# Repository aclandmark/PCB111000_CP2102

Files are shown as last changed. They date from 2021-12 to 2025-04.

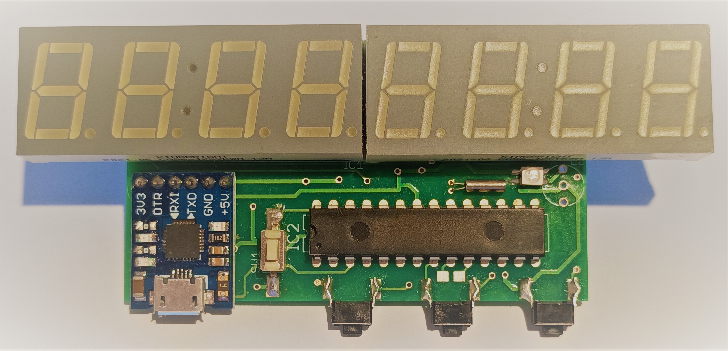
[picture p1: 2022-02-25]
Documents/Photos/PCB_photo_TOP_4.jpg

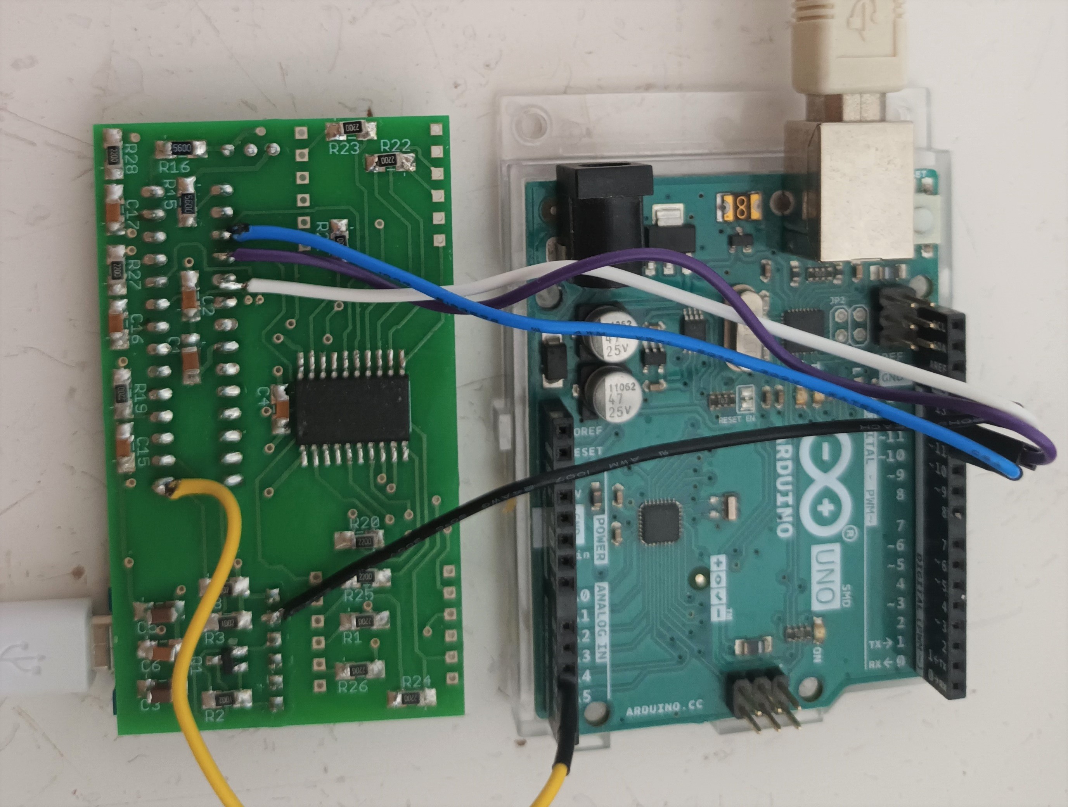
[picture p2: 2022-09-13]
Documents/Photos/Programming_sys_FW_copy.jpg

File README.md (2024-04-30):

# PCB111000_CP2102

PCB111000 has beeen developed as a learning aid for the C language when applied to AVR devices.  
It consists of a USB bridge to communicate with a PC, an 8 digit display and two AVR devices. 
One of the AVR devices (Atmega 328) hosts a programmer and miniOS which drives the display, 
the other (Atmega168), the user device, hosts user projects.

An I2C bus is used to link the two devices.
All user projects are compiled using Arduino, system projects use Arduino or Studio 7 if needed.
The boards are set up using the UNO to host a bespoke programer.  See repository "UNO_as_an_AVR_programer". 

See repository "PCB-111000/1_Documentation/1_PCB 111000 leaflet.pdf" for general information and a block diagram of the original development. 

There are three versions of PCB111000:

PCB_111000_V2 using two Atmega devices and the FTDI FT230XS USB bridge  
PCB_111000_UNO_V2 A simplified plug in version for use with the UNO  
PCB_111000_CP2102 Using one Atmega one ATtiny and a CP2102 module for USB connectivity.  

In PCB_111000_UNO_V2 and PCB_111000_CP2102 the user device is an Atmega328 which hosts
a bootloader as well as the user projects.

In PCB_111000_CP2102 the I2C bus is replaced with a one wire firmware UART.

PCB111000_CP2102 is assembled using the following steps:

	Prior to assembly a UNO loaded with "UNO_AVR_Programmer" is used to
	program an Atmega328:
	
		With a routine that will be used to calibrate the internal 8MHz clock
		and will then be deleted.
		With a bootloader that will be used for all future programming operations
	
	Post assembly a UPDI programmer is uploaded to the Atmega328 which 
	enables the ATtiny1606 to be programmed with the miniOS.

	Calibration of the ATtiny1606 checked and adjusted if necessary
	
	The pcb is now ready to accept user projects.

	At any stage the UPDI programmer can be rienstated to upgrade the miniOS.

SW used to configure PCB_111000_CP2102  
UNO_AVR_Programmer :	see AVR freaks projects 9 Sept 2020 Slighytly modified  
UNO_UPDI_Programmer: 	Originally writen for the UNO but also runs with an 8MHz clock  
			and can be used here

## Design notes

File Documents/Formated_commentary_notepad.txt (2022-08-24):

***
Page 1   PCB_111000_CP2102 (or just the PCB):Press a/k to continue.

Learning with PCB111000 is based on playing with simple programs, getting familiar with the way they are written, understanding them and finally modifying them to make them our own. The programs drive an 8 digit display, generating patterns and numbers and pass data to and from a PC.

Before attempting to begin programming in earnest it is a good idea to read the Introduction and User Guide and of course download the applications suggested there.

Our first project a simple C program is based on JP's Blinky, see JP p30 and chapter 3.   A selection is offered here.  A free-bee is given, just to make sure that everything is working OK. Just follow the instructions given in the user guide.

Why not choose another and type it in. Verify the code and upload it to the pcb (remember Ctrl z, the most useful go back feature).

System crashes: Every effort has been made to prevent these, but if pulsing the reset control switch does not restore the p/r/t/D prompt reconnect the PCB to the PC with this switch held in.

Having got it working pressing Tools/Auto Format will make the code much clearer to read. Why not try several others and then take a look at them and notice a number of features:

#include "First_project_header.h"  	Click on it and see that it contains additional information required by the compiler, including other .h and .c files with essential definitions and resource subroutines  (pn is recommended for opening these). 

The main routine.  This is where the program starts when power is first applied or after a reset.	Move on the page 2 for more features (press a/k).*

***Page 2   More things to take note of in our C programs.		setup_328_HW (Hard Ware):This contains a block of code and is known as (k\a) a macro. Details are given in the header file.	HW requiring setup includes the data pins,	communication between the micros and with a PC	the reset control switch	and watch dog timer(WDT) which automatically reset the micro.	In addition sei() enables interrupts which are required by the one wire link (and will be discussed later).

Unsigned int PORT_1:PORT_1 is the name of a memory location that holds numbers.	The smallest element of computer memory is a bit and can hold either a 1 or a 0. 	Memory is often divided into blocks of 8 bits which can hold numbers between 0 and 255.	16 bits are reserved for PORT_1.	See JP chapter 4 for an introduction.

Hexadecimal numbers (i.e. 0x8000) in which 16 in ordinary counting is equivalent to 0x10 and 256 (16 x 16) is equivalent to 0x100. 	Arithmetic and logic symbols. 	JP gives full definitions of these topics in chapter 4.	However logic quickly gets rather involved and a quick look is all that is recommended at this stage. 

The for loop, the while loop and the if statement which are very important features of C. A good look at JP chapter 5 C Control flow is recommended before moving on from this first project.

Subroutines	One_wire_Tx_2_integers(PORT_1, PORT_1)	which sends data over the one wire link to drive the display.	PRN_16bit_GEN(0) which generates random numbers	Timer_T2_10mS_delay_x_m() which uses a HW timer to generate delays.		Note: Subroutines are called by the main routine or other subroutines. Here we define them as either resource subroutines which are for general use or project subroutines which are written for a particular project.  See JP page 87 chapter 6 for more on subroutines.

break and continue commands:  These are both executed when a particular condition is met.  Break causes the program to exit a for or while loop.  Continue causes it to skip a number of lines of code and jump back to the start of the loop.  See JP page 79.

SW_reset;	This is also a macro. It uses the watch dog timer (WDT) to reset the program so that it repeats endlessly.

Before leaving example 1 why not comment each line stating what it does as a learning aide (See JP p39). 

Having looked at the examples why not mix and match to compose your own code.*

***Page 3   Talking to the PC, introducing the USART (Universal .... Receiver Transmitter module).		Many devices have a receiver transmitter module for communicating with a PC.	See JP page 98 chapter 6 for a few details.	Arduino provides a comprehensive set of functions for using the USART. 	Here basic do it yourself (DIY) functions are used.	This approach provides a good introduction to the data sheet, a vital resource for setting up other things such a timers and interrupts. 

Take a look at subroutine Char_to_PC_Local() and see section 20.11.1 of the data sheet.	UDR0 is the input output (I/O) data register for the USART, it has 16 bits, 8 for write operations and 8 for read.	Data written to UDR0 will automatically be transmitted.	Data that has been received can be obtained by reading UDR0.	UCSR0A is the Control and Status Register A.	UDRE0 (bit 5 of register UCRS0A) is a flag which is set when UDR0 is empty and can accept new data for transmission.	RXC0 (bit 7) is a flag which is set when data has been received and can be read. 

A number of these DIY functions can be found in	Resources_Receiver_transmitter\Basic_IO_and_Timer	They are best viewed using programmers notepad (pn).*

***Page 4   Nine sample programs that transfer data to and from the PC are offered.		A look at each is recommended.	Example 1 simply echoes keypresses to the screen.

Example 2 prints many of the common characters to the screen.	Clicking on the hex button in the receive section of the Bray window shows that each character is represented by a number. See JP p283.

Example 3 prints a file.	Resource "isCharavailable(65)" returns a 1 immediately if a character is received in a 1 second window. Otherwise it returns zero and is called again.	Having received the first character it can then receive any number but will exit (break) if no character is received after a pause of 154mS.

Example 4 introduces character strings and shows they can be sent to the PC.	It also shows how they are stored in arrays (consecutive locations) in memory.	We compose the strings and choose a name for each one.	The compiler adds a 0 to the end of each string.  It also replaces the names (i.e.  message_1) with the address of the first character in the string.	Note the two ways of writing the appropriate the C statements:	The * character indicates that memory location message_1 holds an address.	The [ ] characters indicate that message_3 is an array of characters.	See page 5 for more UART examples.*

***Page 5 More examples of data going to and from the PC.		Example 5 simply prints out the characters together with their numeric equivalents.	Example 6 Converts a number to a string of characters and sends them to the PC and example 7 does the reverse.	These are two very important operations. Take time to understand what is going on. See JP pages 81 to 84 for some help.

Example 8 Uses project subroutines to: Accept a numerical string from the keyboard, convert this to a number which it doubles, reconvert the result to a string and send this to the PC.	All the strings are stored in array Num_string which has 12 memory locations. The subroutines require the address of the first element in this array (hence the use of the * symbols).	Variables preceded by the * symbol are k/a pointers.  See JP ch. 8 for a discussion of pointers.

Example 9 uses repeated division to convert a fraction to decimal.	It calls subroutine divide() which returns the number of outstanding decimal places. It also calculates the result of the division and the remainder (modulo see JP page 51).	Memory for these two variables is provided by the main routine.	The & symbols indicate that the subroutine will not be providing memory for these variables.  It is the address of each variable that is being passed to the subroutine not its value.

As an alternative to the use of pointers (i.e. the * and & symbols), variables can be declared in the header file rather than in the main.  This may be OK for small projects but is not normally considered good practice (see JP page 90).*

***Page 6   Using interrupts: 5 examples are given.		See JP chapter 7 p109 for a general introduction to interrupts.	3A does some calculations and prints out the results when sw2 is pressed. A HW timer running in the background interrupts this process every 100mS. The micro jumps to the ISR (interrupt service routine) and updates the display.	A key press interrupt is also shown enabling users to to manipulate the display manually.	We see that the interrupt enables 2 processes to run at once.

Look at the 100mS_clock_tick() subroutine.	The timer is configured as a counter which counts from 0 to 12500.	TCCR1B sets a timer clock to 125KHz so it takes 100ms to complete counting, raise an interrupt and start again.	Open up the data sheet section 16.11 to see the registers. We leave most of them alone but set TCCR1B, TCNT1, OCR1A and TIMSK1.

3B Target practice looks at interrupts generated by pressing one of the user switches.	PCI stands for pin change interrupt.	Look at the header file for definitions of the macros.	See the data sheet sections 13.2.4 and 1 for details of the PCI registers.

3C Reaction time tester:Nothing new here, just included for a bit if extra practice.	Press SW2 and release immediately that the leds line up to get the display to flash.

3D Multi display:This includes PCI and timer interrupts as well as the one wire comms interrupt.	Multiple interrupts can easily cause trouble. To avoid this the PCI also resets the micro. Before doing so it writes to the EEPROM. After the reset it reads the EEPROM so that it knows which switch was pressed.	EEPROM is a special area of memory that survives power down and reset, which both usually result in all registers being reset to zero.

3E Is an interrupt driven key press logger that also drives the display.	Projects 3D and E include the volatile declaration. This is because variables are being changed by an ISR.  Unlike for a subroutine the compiler cannot anticipate that the ISR will be called. The variables are therefore declared to be volatile as a warning to the compiler.*

***Page 7   Exploring logic and binary operations.		Two programs Bit_ops_1 and 2 are used to demonstrate how individual bits can be read, set, reset or changed.	These operations are needed to configure HW items such as the USART, and Timers and also to monitor their status (i.e. is there USART data waiting to be received).

Bit_ops_1 uses the display and random number generator to investigate the AND, OR, Exclusive OR and NOT operations.	Bit_ops_2 combines these operations with the shift function to set or read individual bits.

As a practice exercise in logic, multiple addition and subtraction are used in program_3 to implement multiplication and division (these operations are usually carried out in HW or by compiler generated code). 

As a final example the display is used to display positive and negative 8 bit numbers in binary and decimal form.*

***Page 8   Using the Arduino PC comms library:		Arduino provide a suite of programs that pass data to and from a PC. These will probably be the sensible choice for use with the Arduino compiler.	Integer and floating point numbers are supported.	Easy extension to include scientific numbers is implemented in these examples.

Three additional examples are included:	The first explores prime numbers. The theory for these was developed by the ancient Greeks. Their method for obtaining them is still probably the best for us use here. 

The second provides an estimate for pie.  The area of a circle is computed by placing it over a fine grid of squares and counting them.	

The third uses a power series to compute log/antilog functions so that any positive scientific number can be raised to an arbitrary power.   If the result is either too large or small the program times out.  An interrupt is generated and the resulting ISR, writes to the EEPROM, before issuing a SW_reset.	When the program resets it reads the EEPROM and issues the appropriate user prompt.*

***Page 9   The 8 digit display and IO:		Obviously Arduino does not provide library functions to drive the display, so it is necessary to revert to DIY programming.	The purpose of the first 2 programs is to demonstrate how numbers are constructed from the display segments.	Program 3 defines each digit in terms of a string as has previously been done with messages.	The user enters a digit at the PC.	The appropriate string is selected.	Segments defined by the string are are illuminated.

In the remaining projects the complexity of driving the display is handled by the mini-OS that resides on the Attiny1606.	Two of these are used to enter data from the PC keyboard and two from the user switches.*

***Page 10   Timers    Here a selection of timers/clocks are developed.		Accuracy is provided by a watch crystal that beats 32768 times a second.	Register TCCR2B (see section 18.1.2) is used to reduce the crystal frequency to 1024 beets per second which are counted by timer/counter T2.	The counter advances by 102 in 99.61mS (~100mS) after which an interrupt is raised.	It advances by 918 in 896.5mS (~900mS).	To ensure accuracy over a 1 second interval the counter must advance by a further 106 (103.5mS) before the 1 second interrupt is raised.

In the first example time is simply recoded as a string, and in the second a counter is set up that records elapsed time in seconds. In the third example much of the time keeping burden is transferred to the mini-OS.	Two more examples are included,  one is a stand-a-lone clock, in which time is entered and adjusted using the user switches and the other is a stop watch.*

***Page 11   Reset options		The HW includes a timer k/a the watch dog timer (WDT).  This counts from zero to a user defined value after which it issues a reset pulse.   Provided that it is reset frequently enough there need be no reset.  

Arduino offers three modes for the WDT.		It can be initiated as in the macro "setup_watchdog" (see the project header file).	If it is allowed to time out the project will be reset.		It can be initiated with an interrupt (see for example "One_25ms_WDT_with_interrupt").	The ISR (interrupt service routine) might write to EEPROM before issuing a SW_reset.		If the ISR is missing program control willl jump to location 0x0000, the start of the program.	This is important for us because a reset takes program control to the boot loader not the start of the user project (0x0000).

PCB111000_CP2102 uses the macro "SW_reset" to implement a planned reset.	It uses "One_25ms_WDT_with_interrupt" with no ISR to recover from an unplanned reset or system crash.

The micro includes an MCU status register (MCUSR).	This records the source of the reset which can be	POR (power on reset)	WDT	External reset (not used here)	Low supply voltage (not used here).	The bootloader reads this to determine whether the reset is due to the WDT or POR	It uses the EEPROM to determine whether to jump to the user program or continue with the bootloader.

Example 8A explores the basic operation of the reset function provided by PCB111000_PC2102	

Example 8B sums cosine waves to generate a pulse function.  This is an example of the micro working flat out with an 8MHz clock.  No wonder many applications require a much faster clock.  The various reset functions are used to control its operation.*

***Page 12   That's it for PCB11000_CP2102:	Much ground still to cover, many new things to explore, but hopefully enough ground has been covered to wet the appetite for more detailed and systematic study.

Click on Arduino Help/Reference to see that we have barely scratched the surface of what Arduino has to offer.	There is of course also the Atmel Studio free development system.  I would certainly not want to be withour either.	

Of course the great strength of the UNO is that it comes with a bootloader.	However why not experiment with UNO_AVR_Programmer also posted on AVR freaks.	Even download free PCB design SW and make your own board!*

***Page 13   Not used.*

***Page 14   Not used.*

***Page 15   Not used.*

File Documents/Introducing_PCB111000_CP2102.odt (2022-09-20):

Introducing PCB111000_CP2102

PCB111000_CP2102 is a cut down version of PCB_111000_UNO posted by osbornema on 18 July 2020. It is designed to provide an introduction to C programming for AVR devices and consists of:

A CP2102 module with Rx/Tx and power provided on a 6 pin header

An Atmeg328 for user programs

An ATtiny 1606 that drives an 8 digit seven segment display.

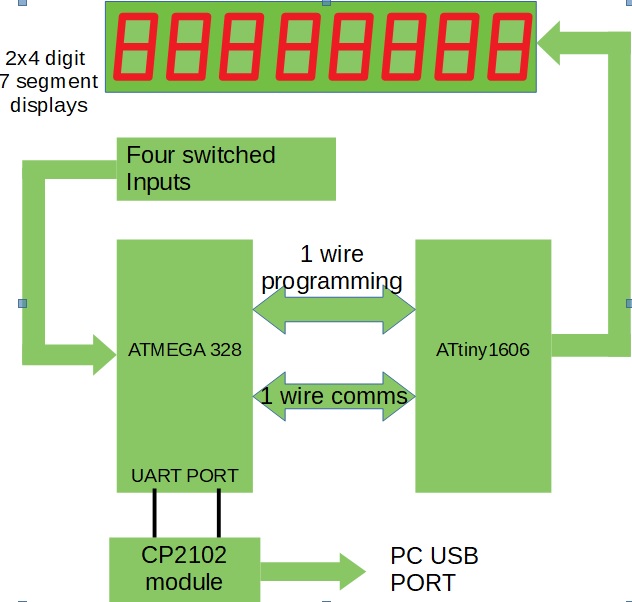
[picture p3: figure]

| System diagram for PCB111000_CP2102 The Atmega 328 hosts: A Hex/text bootloader An optional UPDI programmer User programs Text commentary for several sample programs. A default program provided for test purposes. The ATtiny1606 Drives the display Provides resources for the user projects One of the switches controls reset and display intensity. The others are or data entry.

System projects

| Name | Compiler | Platform | Task
1 | UNO_programs_328 | Arduino | UNO | Uploads bootloader and provides time standard for Atmega 328 calibration.
2 | UNO_Calibrates_328 | Arduino | Atmega328 | Calibrates 328 against the UNO crystal
3 | CP2102_UPDI_Programmer | Arduino | Atmega328 | Uploads mini-OS to ATtiny1606
4 | CP2102_mini-OS | Studio 7 | ATtiny1606 | Drives display and provides user services
5 | cal_one_wire_comms | Arduino | Atmega328 | Matches 328/1606 baud rates
6 | CP2102_bootloader | Studio 7 | Atmega328 | Loads user projects and reads the commentary
7 | FP_arithmetic | Arduino | Atmega328 | Test project
8 | Recal_328_using_crystal | Arduino | Atmega328 | Check calibration post pcb assembly

Note: All projects are closely based on previous versions already posted on AVR freaks.


| Fig 1 Photos of PCB111000_CP2102 Note that tracks are provided for either surface mount or leaded Red/Green LED and watch crystal The vertical switch is the reset control switch. The horizontal switches are user switches sw1, sw2 and sw3 counting from the middle of the pcb. RX/Tx leds on the CP2102 module can be disabled if they are found to be too bright by removing their series resistors as in the photograph.

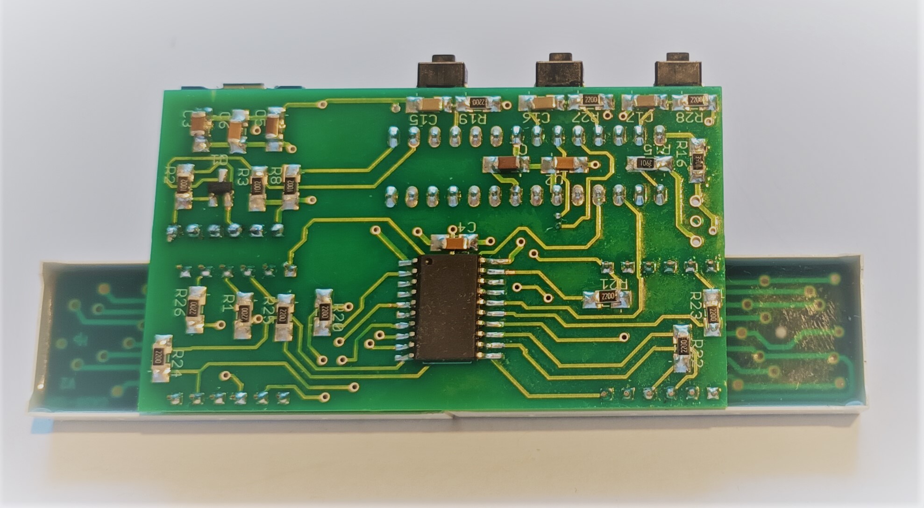
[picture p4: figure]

The Project PC

There are two essential software applications that must be downloaded onto this PC. They are:

The Arduino development environment. Go to https://www.arduino.cc/en/software and download it from the Microsoft store.

Bray++ version 20130820 which can be downloaded from https://www.sites.google.com/site/terminalbpp/

Almost as important are

The portable version of Programmers notepad which can be downloaded from

http://www.pnotepad.org/download/.

An excellent text written by Joe Pardue that can be downloaded from

https://epdf.pub/c-programming-for-microcontrollers.html

The Atmega data sheet that can be downloaded from

https://www.docdroid.net/Q6jfzd3/atmega48a-pa-88a-pa-168a-pa-328-p-ds-ds40002061a-pdf

PCB manufacture: Generating the Gerber files

The Eagle pcb design tool must first be downloaded.

A free version is available from Autodesk which can be used to process two layer boards of a limited size. Go to https://www.autodesk.com/products/eagle/free-download

Place the Eagle board and schematic files in any suitable folder (to be referred to as the Project directory).

Open the Eagle control panel

Click on CAM Jobs then examples and double click on example_2_layer.cam

Tick the Export to Project Directory box

Click on Select board

Navigate to the project directory and open the board file

Click on Process Job then Open folder

A CAMOutputs folder should have been added to the project directory. This will contain the Gerber and drill files needed to get the pcb manufactured.

Recommended PCB assembly steps

Solder on all SM resistors, caps, the FET and the ATtiny 1606 to the pcb underside.

Check the CP2102 module by connecting it to a PC and detecting it in “device manager” then add it to the pcb as follows

Solder a 6 pin vertical header to the upper surface

Slide off the plastic spacer

Trim the vertical pins to a length of several mm

Attach the CP2102 module via the header pins

Place a piece of fine card between the module and pcb

Solder on the module and remove the card.

Discard the right angled header

Add remaining components. Note however: addition of the displays and user switches can be delayed until the mini-OS has successfully been uploaded to the ATtiny.

Continuously examine pcb for solder splashes, dry joints and other damage.

Setting up a new PCB111000_CP2102

Having completed assembly minus the display and user switches use jumper wires (Radio Spares 791-6463) to connect the PCB to a UNO as shown below and connect both the UNO and CP2102 module to the project PC.


| Interconnections
| Colour | UNO pin | PCB: Atmega pin
| Yellow | A3 | 1
| White | 13 | 19
| Mauve | 12 | 18
| Blue | 11 | 17
| Black | GND | 0V
Fig 2 UNO and PCB111000_CP2102 configured to upload the mini_OS and bootloader and calibrate the Atmega328 internal RC clock and one wire comms link.

Setup Steps:

1. Program the UNO

Open the Arduino project “UNO_programs_328” and upload it to the UNO.

Close “UNO_programs_328” and open two instances of the Br@y++ terminal program.

Use them to connect to the UNO and CP2102 modules at speeds of 38.4 kBaud (otherwise use default settings).

The UNO generates prompt “s s s…….”

Keypress ‘s’ generates the following response:

Atmega 328P detected.

To program flash: press -P- for bootloader or -p- for other routines,

Press -t- to run 328 calibration routine,

Press -r- for other routines,

Press -V- to read flash or -x- to escape.

2. Calibrate the Atmega 328

Press -p- and upload “UNO_Calibrates_328”

Press -t- to run the calibration routine.

See Fig 3 below for typical terminal dialogues

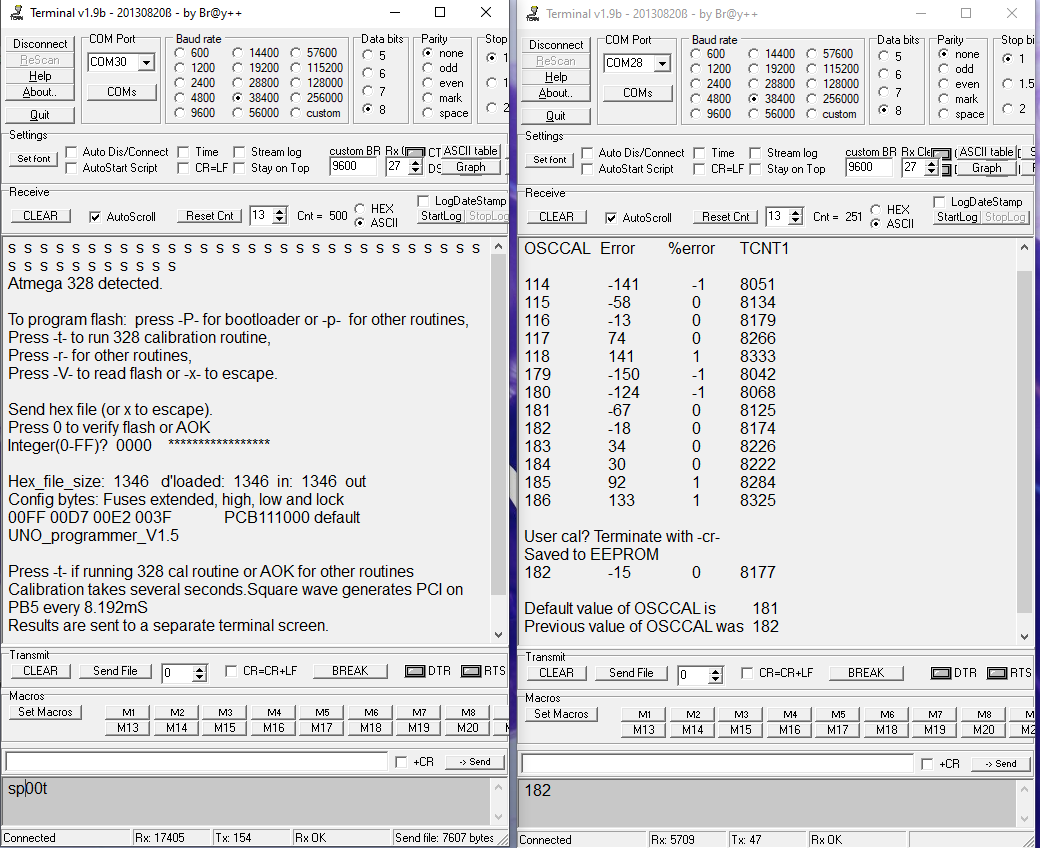
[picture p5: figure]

Fig 3 Terminal dialogues generated when the Atmega328 is calibrated. Settings are: 8 data bits, 1 stop bit, no parity and no handshaking

3. Upload the mini-OS

Press the UNO reset button to restore the “s s s…….” prompt.

Upload and run “CP2102_UPDI_Programmer”

Power cycle the CP2102 module and reduce its baud rate to 14.4k.

In response to user prompt “R R R ….” press -r-, -a-, -y-, -y- and upload “CP2102_miniOS”

See Fig 4 for a typical terminal dialogue.

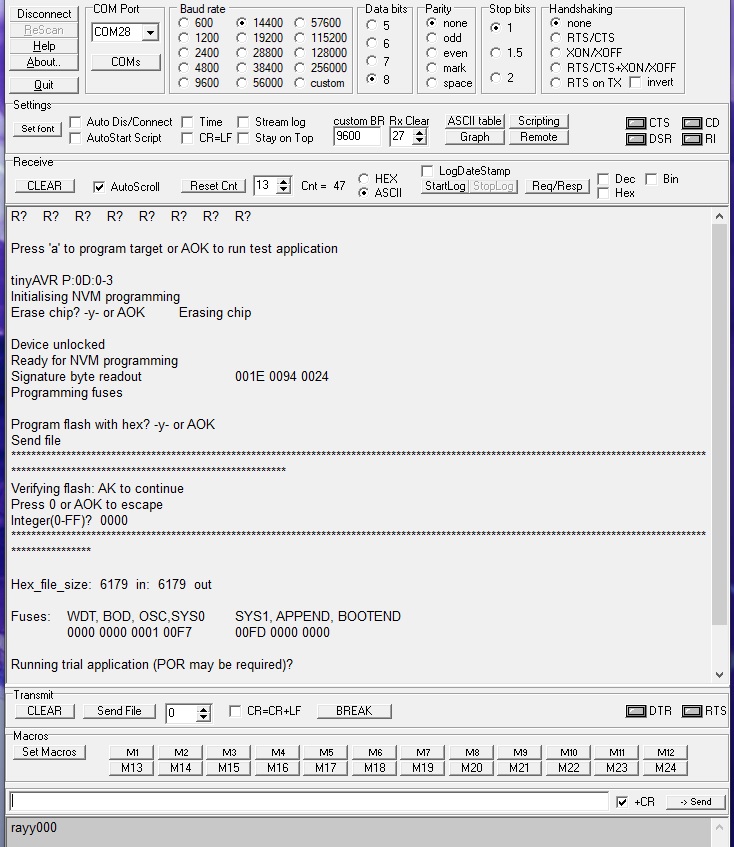
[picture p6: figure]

Fig 4 Terminal dialogue: Using “CP2102_UPDI_Programmer” to upload “CP2102_miniOS”

4. Remaining steps

Set CP2102 baud rate to 57K

Upload and run “calibrate the one wire comms”

Upload “Bootloader_Full_hex” (be sure to use key press -P- in place of -p- to initiate upload).

Pulse the reset control switch and check for the p/r/t/D user prompt

Disconnect the UNO

Upload and run “Recal_328_using_crystal”. Result should be within +/- 2 of that already obtained.

Power cycle the CP2102 module with the reset control switch pressed to restore the “p/r/t/D...” prompt.

Upload and run FP_arithmetic.ino.standard

Unsolder flying leads and fit display modules and users witches.

At p/r/t/D prompt press -D- to obtain the default application and check display.

Press and hold the reset control switch to toggle the brightness.

POR to restore low brightness.

Upload and run “Project 6F_FPN_from_IO” to check operation of switches.

At p/r/t/D prompt press -T- and upload the commentary.

Upload and run “Project 5E_e_power_series” then check that the commentary has not been corrupted.

Operation of the reset control switch

When power is applied program control will jump to the user project.

To restore the “p/r/t/D...” prompt

power cycle PCB111000_CP2102 with the reset control switch pressed

or

pulse the reset control switch which is usually sufficient

To reset the user project hold the reset control switch down until the dual led illuminates.

Display intensity can also be changed by holding the reset control switch down until the dual led extinguishes.

User projects

These are all composed using Arduino.

Click on Sketch/Export compiled Binary/ rather than Sketch/Upload.

For each project two files are generated, for example

8B_Pulse_train_generator.ino.standard

and

8B_Pulse_train_generator.ino.with_bootloader.standard

take care to delete the bootloader version and upload the other one at the “p/r/t/D...” prompt as described above pressing -p- to upload it and -r- to run it and using a baud rate of 57.6K.

Reading the commentary

Press -t- at the p/r/t/D prompt

Key in page number 1 to 12.

Press any key to scroll through the page until the p/r/t/D prompt is restored.

Commentary index

Page number | Projects
1 | 1_first_project
2 | 1_first_project
3 | 2_Receiver_Transmitter_Basic
4 | 2_Receiver_Transmitter_Basic
5 | 2_Receiver_Transmitter_Basic
6 | 3_Interrupts_and_switches
7 | 4_binary_and_bit_operations
8 | 5_Arduino_PC_comms_library
9 | 6_The_8_digit_display_and_IO
10 | 7_Timers
11 | 8_Resets
12 | Concluding remarks

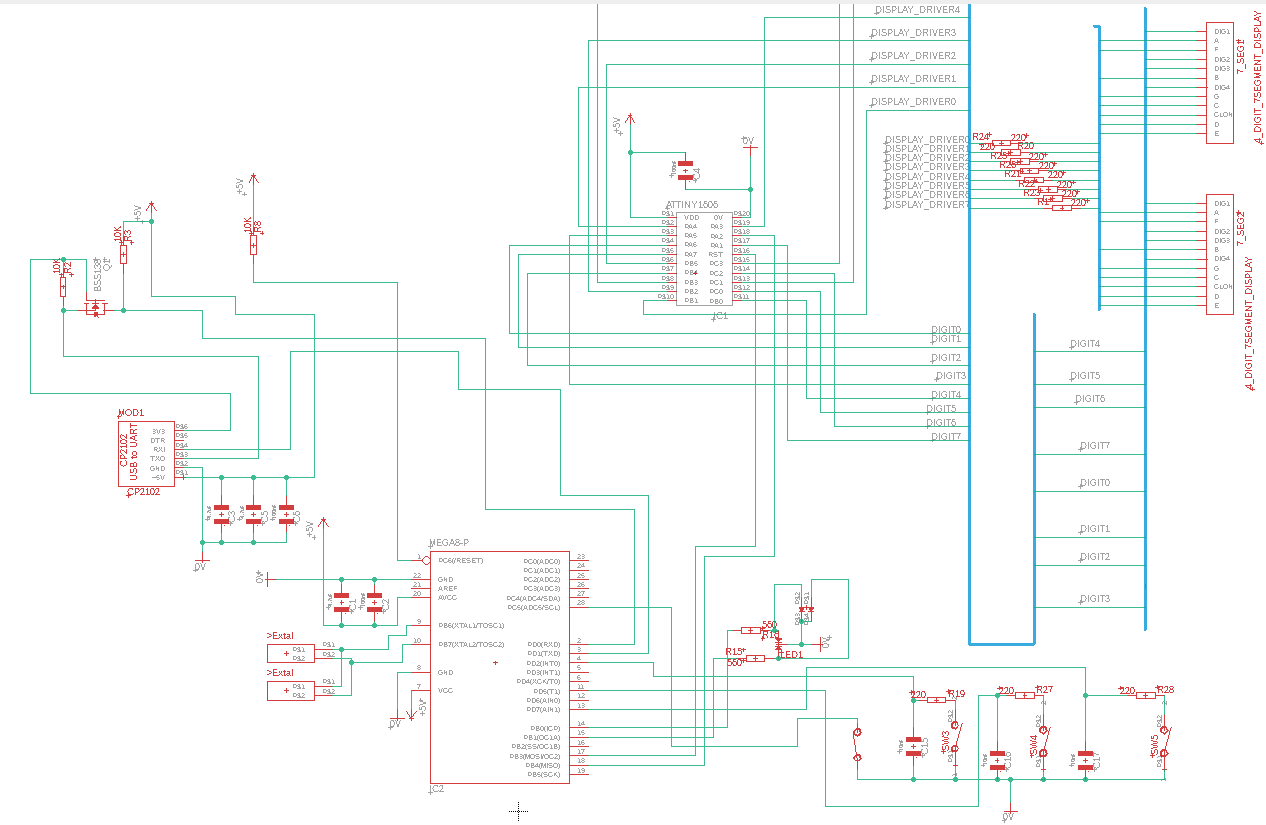
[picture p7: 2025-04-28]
Manufacuring_drawings/Schematic.bmp

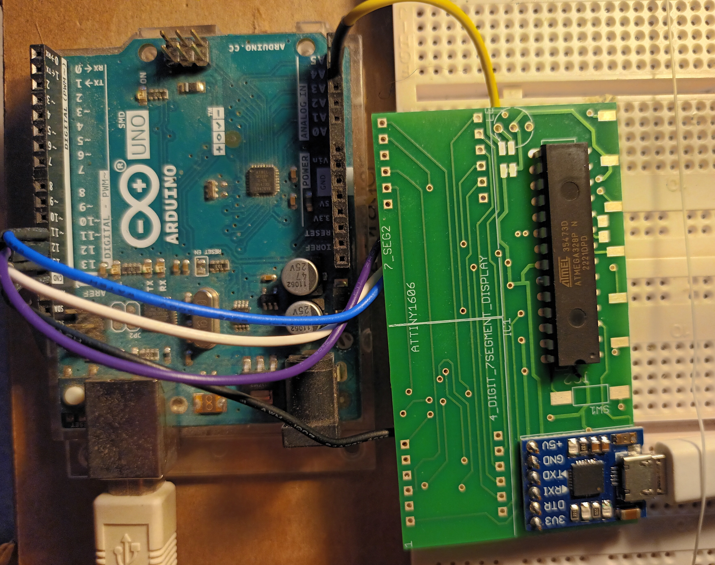
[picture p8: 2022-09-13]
Documents/Photos/Programming_PCB111000_CP2102_top_side.jpg

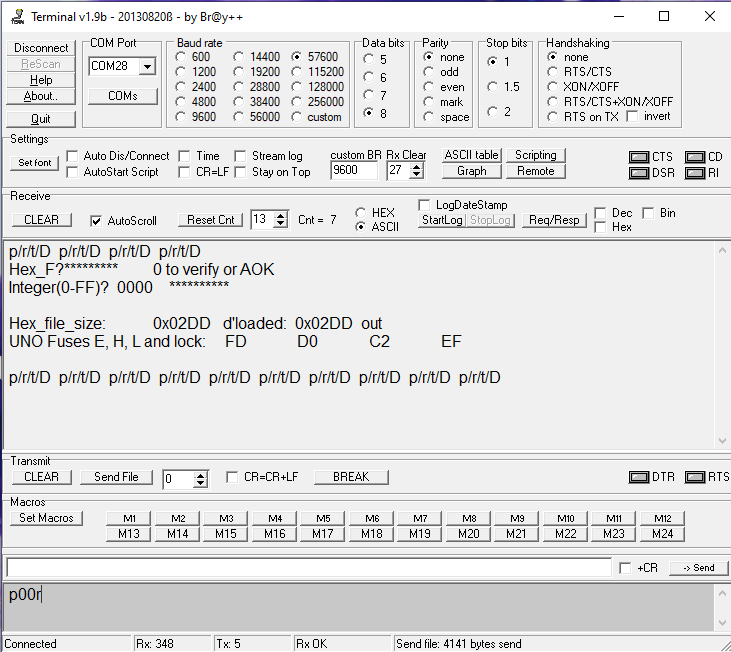
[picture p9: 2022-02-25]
Documents/Photos/Bray_screen_shot_1.bmp

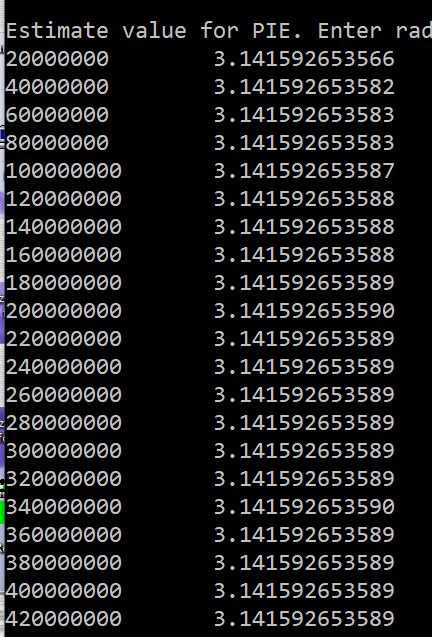
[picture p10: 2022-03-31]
Documents/Code_blocks_estimates_pie_in_Two_mins.bmp

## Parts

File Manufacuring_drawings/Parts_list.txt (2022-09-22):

Display modules
CA56-12SYKWA	RS 872-1954		Floating point version

MOD1	From eBay	
CP2102 MICRO USB to UART TTL Module 6Pin Serial Converter

IC1	ATtiny1606 (SOIC)
IC2	Atmega 328 (DIP)

Q1	BSS138, 2N7002 (SOT23 devices) or similar

LED 1	Common cathode RS228-5764 or
Surface mount dual led	RS 174-9789

Watch Crystal	
RS  171-0553
or surface mount RS 171-0335	(not tested)

Switches from https://www.rapidonline.com/
SW1 		51-0709		Normally Open push button (SM)
SW3,4,5		51-0711		Normally Open push button (with pins)

R1, R20-26	220R	1206
R19, R27-8	220R	1206	

R15, 16		560R	1206

R2, R3, R8	10K	1206

C1, C3, C5 	4.7uF	1206

C2, C4, C6 	100nF	1206

C15-17		10nF	1206

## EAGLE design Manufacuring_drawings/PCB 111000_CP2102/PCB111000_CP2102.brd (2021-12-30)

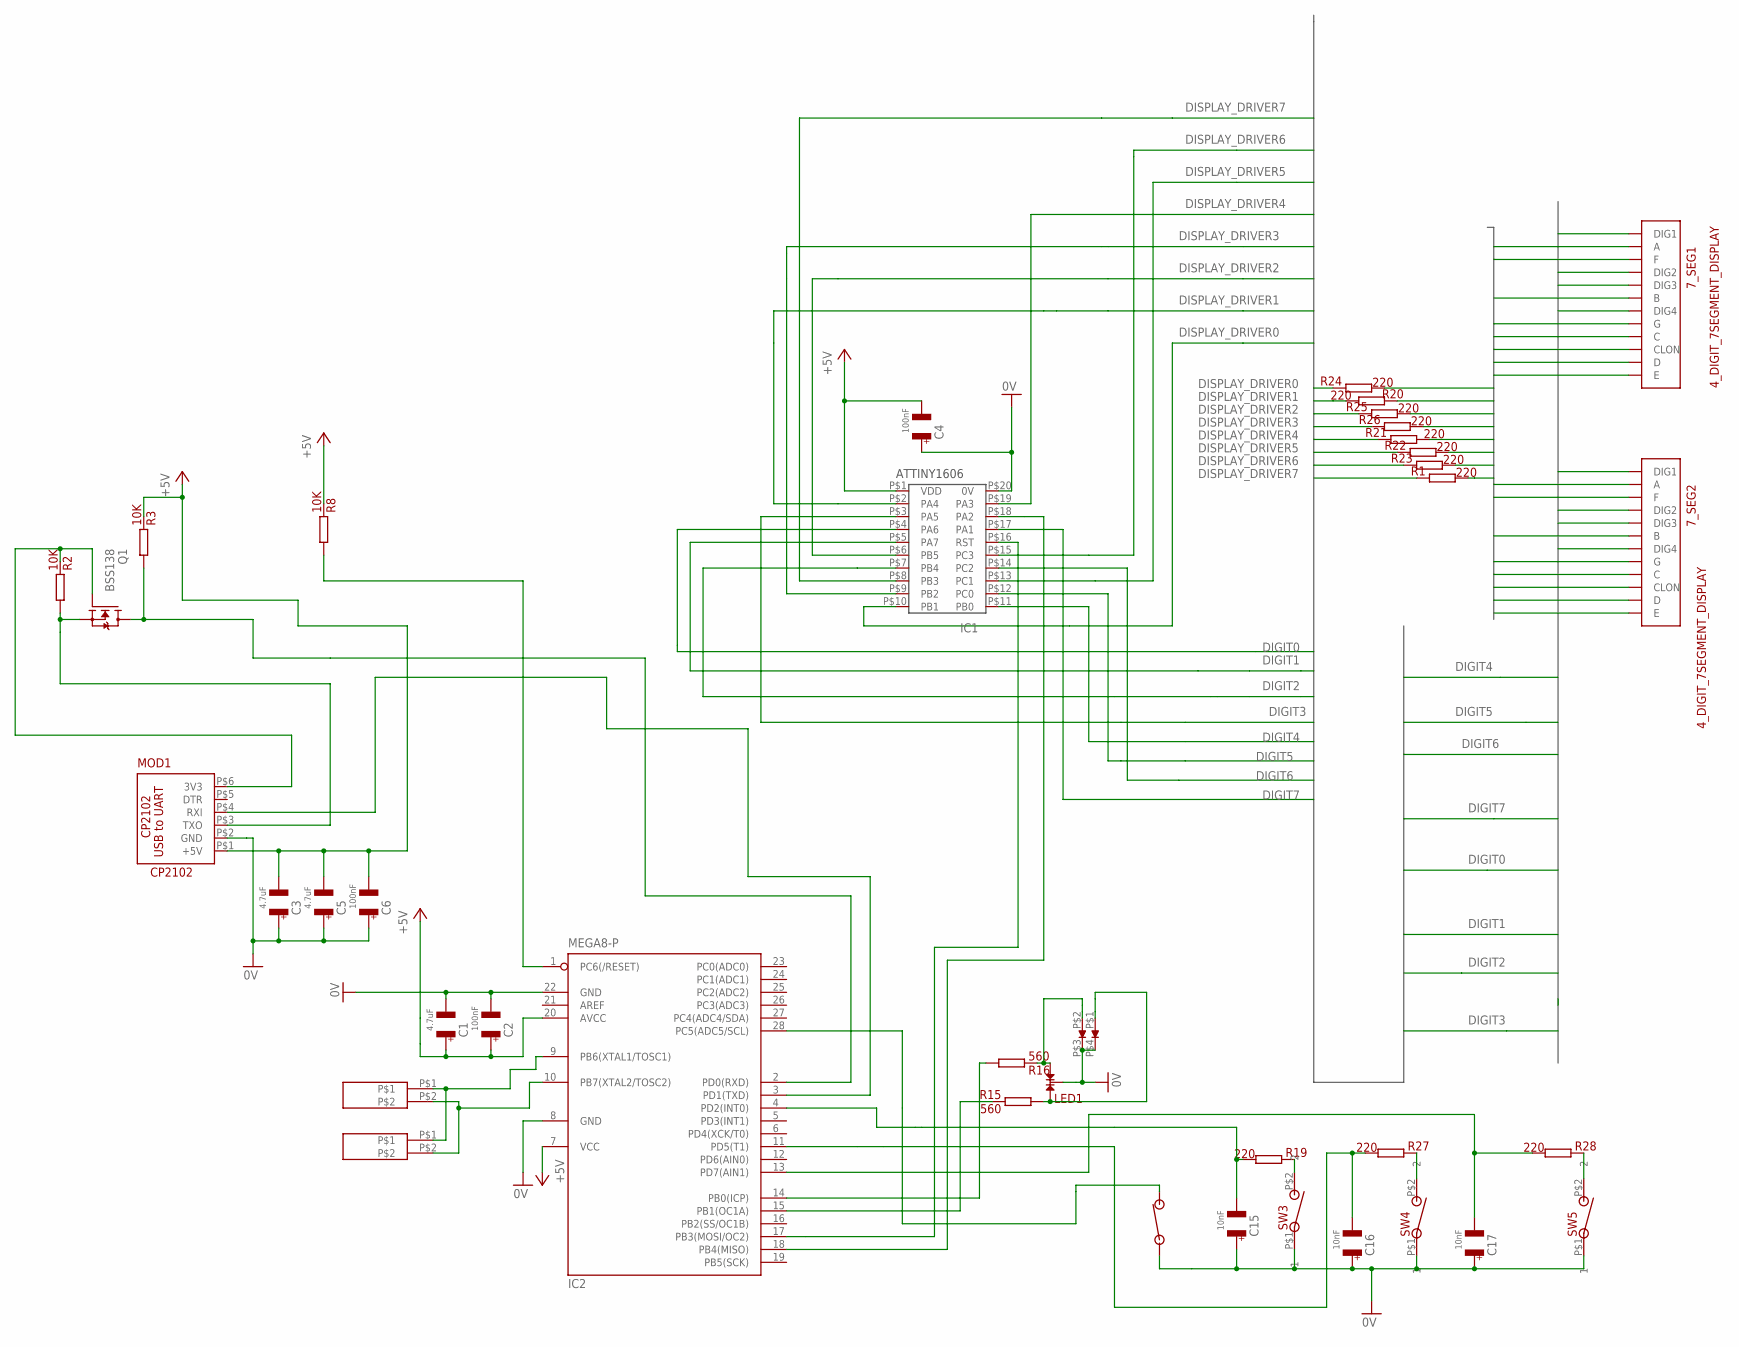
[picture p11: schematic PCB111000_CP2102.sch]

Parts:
7_SEG1, 7_SEG2: 4_DIGIT_7SEGMENT_DISPLAY
C1, C3, C5: 4.7uF; 1206@1
C2, C4, C6: 100nF; 1206@1
C15, C16, C17: 10nF; 1206@1
IC1: ATTINY1606
IC2: MEGA8-P; DIL28-3
LED1: LED; CA_DUAL_LED
MOD1: CP2102
Q1: BSS138; SOT23
R1, R19, R20, R21, R22, R23, R24, R25, R26, R27, R28: 220; 1206@1
R2, R3, R8: 10K; 1206@1
R15, R16: 560; 1206@1
SW1: NO_SW; SM_NO_PUSH_BUTTON
SW3, SW4, SW5: NO_PB_1; RE51-0711
U$1: XTAL
U$2: DUAL_SM_LED; SM_DUAL_LED
U$3: SM_XTAL

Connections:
0V: C1.P$2 (2), C2.P$2 (2), C3.P$1 (1), C4.P$1 (1), C5.P$1 (1), C6.P$1 (1), C15.P$1 (1), C16.P$1 (1), C17.P$1 (1), IC1.P$20 (0V), IC2.8 (GND), IC2.22 (GND), LED1.2, MOD1.P$2 (GND), SW1.P$1 (1), SW3.P$1 (1), SW4.P$1 (1), SW5.P$1 (1), U$2.P$3, U$2.P$4
+5V: C1.P$1 (1), C2.P$1 (1), C3.P$2 (2), C4.P$2 (2), C5.P$2 (2), C6.P$2 (2), IC1.P$1 (VDD), IC2.7 (VCC), IC2.20 (AVCC), MOD1.P$1 (+5V), R3.P$2, R8.P$2
DIGIT0: 7_SEG1.P$12 (DIG1), IC1.P$4 (PA6)
DIGIT1: 7_SEG1.P$9 (DIG2), IC1.P$5 (PA7)
DIGIT2: 7_SEG1.P$8 (DIG3), IC1.P$7 (PB4)
DIGIT3: 7_SEG1.P$6 (DIG4), IC1.P$3 (PA5)
DIGIT4: 7_SEG2.P$12 (DIG1), IC1.P$11 (PB0)
DIGIT5: 7_SEG2.P$9 (DIG2), IC1.P$12 (PC0)
DIGIT6: 7_SEG2.P$8 (DIG3), IC1.P$14 (PC2)
DIGIT7: 7_SEG2.P$6 (DIG4), IC1.P$17 (PA1)
DISPLAY_DRIVER0: IC1.P$10 (PB1), R24.P$2
DISPLAY_DRIVER1: IC1.P$2 (PA4), R20.P$1
DISPLAY_DRIVER2: IC1.P$6 (PB5), R25.P$2
DISPLAY_DRIVER3: IC1.P$9 (PB2), R26.P$2
DISPLAY_DRIVER4: IC1.P$19 (PA3), R21.P$2
DISPLAY_DRIVER5: IC1.P$13 (PC1), R22.P$2
DISPLAY_DRIVER6: IC1.P$15 (PC3), R23.P$2
DISPLAY_DRIVER7: IC1.P$8 (PB3), R1.P$2
unnamed: IC2.14 (PB0(ICP)), R16.P$1
unnamed: IC2.15 (PB1(OC1A)), R15.P$2
unnamed: LED1.1, R15.P$1, U$2.P$1
unnamed: LED1.3, R16.P$2, U$2.P$2
unnamed: IC2.28 (PC5(ADC5/SCL)), SW1.P$2 (2)
unnamed: IC1.P$16 (RST), IC2.17 (PB3(MOSI/OC2))
unnamed: R27.P$2, SW4.P$2 (2)
unnamed: R19.P$2, SW3.P$2 (2)
unnamed: C15.P$2 (2), IC2.4 (PD2(INT0)), R19.P$1
unnamed: IC1.P$18 (PA2), IC2.18 (PB4(MISO))
unnamed: C17.P$2 (2), IC2.13 (PD7(AIN1)), R28.P$1
unnamed: IC2.9 (PB6(XTAL1/TOSC1)), U$1.P$1, U$3.P$1
unnamed: IC2.1 (PC6(/RESET)), R8.P$1
unnamed: IC2.3 (PD1(TXD)), MOD1.P$4 (RXI)
unnamed: MOD1.P$3 (TXO), Q1.2 (S), R2.P$1
unnamed: R28.P$2, SW5.P$2 (2)
unnamed: IC2.10 (PB7(XTAL2/TOSC2)), U$1.P$2, U$3.P$2
unnamed: MOD1.P$6 (3V3), Q1.1 (G), R2.P$2
unnamed: C16.P$2 (2), IC2.11 (PD5(T1)), R27.P$1
unnamed: IC2.2 (PD0(RXD)), Q1.3 (D), R3.P$1
SEVEN_SEG0: 7_SEG1.P$11 (A), 7_SEG2.P$11 (A), R24.P$1
SEVEN_SEG1: 7_SEG1.P$7 (B), 7_SEG2.P$7 (B), R20.P$2
SEVEN_SEG2: 7_SEG1.P$4 (C), 7_SEG2.P$4 (C), R25.P$1
SEVEN_SEG3: 7_SEG1.P$2 (D), 7_SEG2.P$2 (D), R26.P$1
SEVEN_SEG4: 7_SEG1.P$1 (E), 7_SEG2.P$1 (E), R21.P$1
SEVEN_SEG5: 7_SEG1.P$10 (F), 7_SEG2.P$10 (F), R22.P$1
SEVEN_SEG6: 7_SEG1.P$5 (G), 7_SEG2.P$5 (G), R23.P$1
SEVEN_SEG7: 7_SEG1.P$3 (CLON), 7_SEG2.P$3 (CLON), R1.P$1

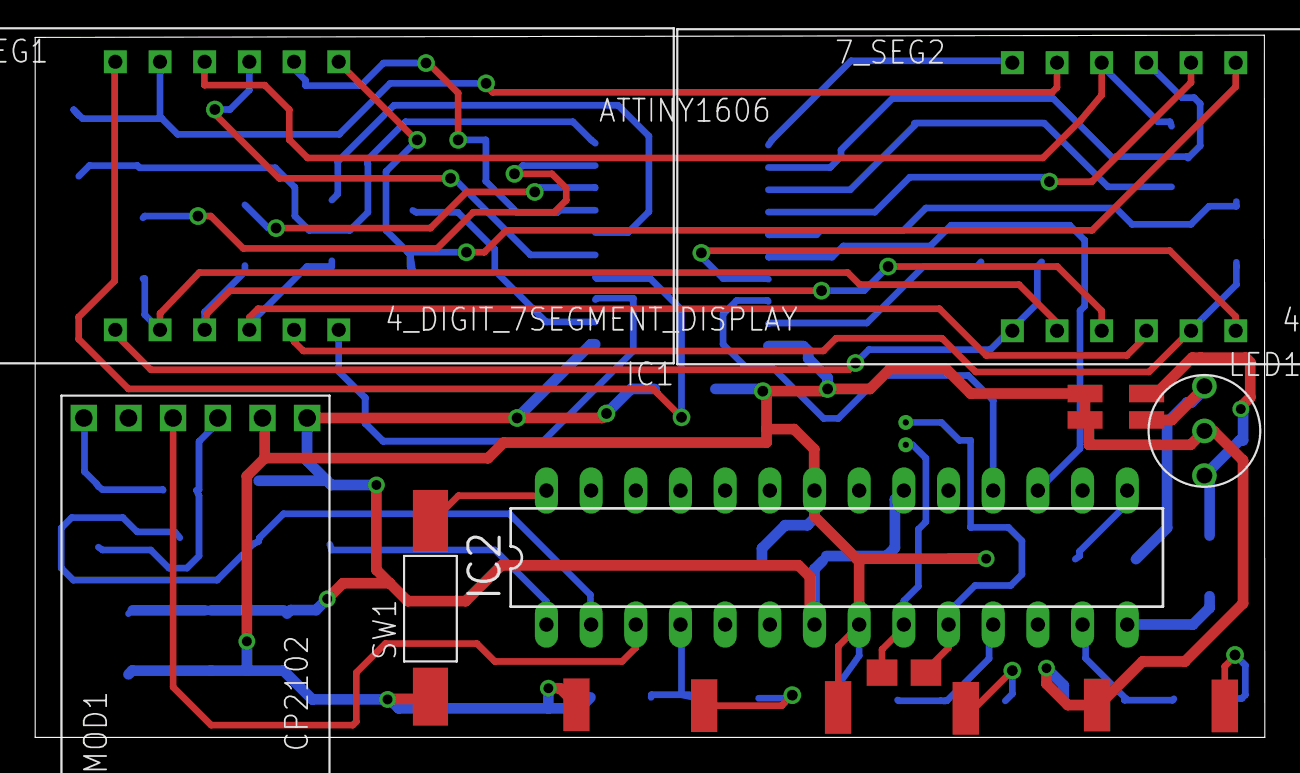
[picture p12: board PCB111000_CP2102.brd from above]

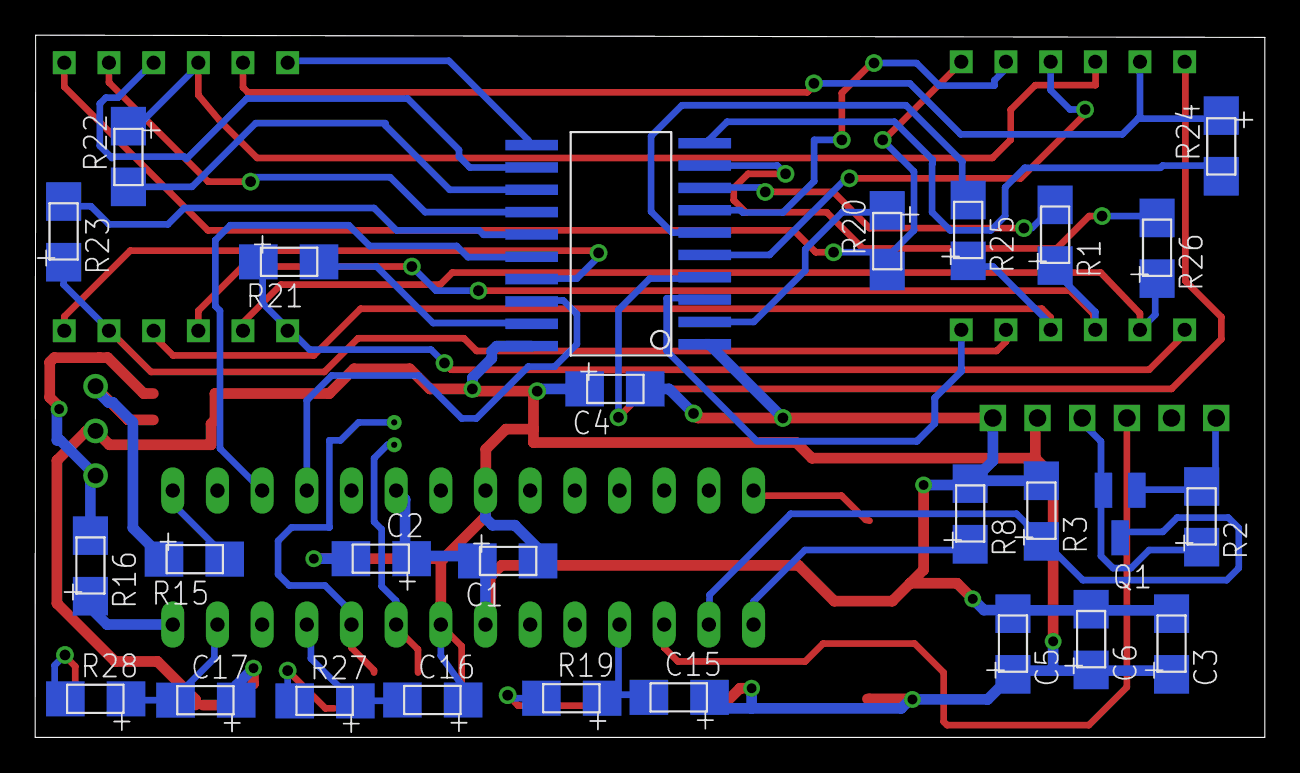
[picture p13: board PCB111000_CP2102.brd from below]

Board: 2 copper layers, 69.9 x 39.9 mm, 39 parts (27 on the bottom side), 46 nets.

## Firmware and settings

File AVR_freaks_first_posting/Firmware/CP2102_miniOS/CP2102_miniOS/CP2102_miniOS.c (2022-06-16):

/*
Program runs on Attiny1606
and is compiled using default Studio 7 compiler settings


Note: This program is to be compatible with user projects running on an Atmega328 clocked at only 8MHz
The peripheral clock frequency must therefore be reduced from 2MHz to 1MHz.
Brightness control settings must be reduced from 500 and 3500 to 250 and 1750

Note:The one wire FW UART now runs at 5KHz (i.e. not 10KHz) and the time per transaction is now 2mS
The display multiplexer period  is still 2mS (to avoid flicker) but a transaction takes 2 periods rather than one  

EEPROM use:	
	0xFF	Brightness control high byte
	0xFE	Brightness control low byte
	0xFD	Reset control

*/


#include "Project.h"
int mag(int);


int main(void){
	
	char null_bit_counter;										//Counts number of blank display digits
	int array_ptr;												//Points to display digits
	
	
	
	
	CPU_CCP = 0xD8;												//Config change protection key
	CLKCTRL_MCLKCTRLB = CLKCTRL_PDIV_16X_gc | 1;				//Generates 1MHz Peripheral clock
	
	if(RSTCTRL.RSTFR & RSTCTRL_PORF_bm)							//If POR reset brightness to low
	{RSTCTRL.RSTFR |= RSTCTRL_PORF_bm;
	brightness_control = 150;
	save_brightness_control;}				
	else 														//If non POR reset maintain brightness as set by user
	{restore_brightness_control;}
		
   	PORTA.DIR &= ~PIN2_bm;										//Configure comm port as input
   	 PORTA.OUT &= ~(PIN2_bm);									//I/O pin low when configured as output
   	 PORTA.PIN2CTRL |= PORT_PULLUPEN_bm;						//Pull-up enabled 
   
   stop_watch_mode = 0;											//Default timer display is clock   
   
   sei();
   Start_TCA0();												//Display (2mS) tick rate
   	
	while(1){
		while(!(transaction_complete));							//Wait here for requests from the UNO
		transaction_complete = 0;
		busy_flag = 1;											//Do not contact UNO until data processing is complete
		
	switch (transaction_type){									//Transaction complete: Process the data
	
	case 'a': break;											//One_wire_Tx_2_integers()
	case 'b': I2C_Tx_any_segment; break;			
		
	case 'A':													//When "cr" detected convert string from UNO to long number
	if(cr_keypress == 1){
	cr_keypress = 0;
	display_buffer2temp;										//Reverse string prior to conversion to binary
	Long_Num_to_UNO = atol(temp_buffer);	
	for(int m = 0; m <= 3; m++)
	data_byte[m] = Long_Num_to_UNO >> (8*(3-m));}				//Split long number into 4 bytes for re-transmission
	break;
		
	case 'B':													//When "cr" detected convert string from UNO to float
	if(cr_keypress == 1){
	cr_keypress = 0;
	check_for_dp;
	Add_dp_if_missing;											//FP arithmetic requires numbers with a dp
	display_buffer2temp;										//Reverse string prior to conversion to a FPN
	extract_dp;													//Display merges the dp with a digit  											
	Float_Num_to_UNO = atof(temp_buffer);
	char_ptr = (char*)&Float_Num_to_UNO;						//Split the number into bytes ready for return to the UNO
	for (int m = 0; m <= 3; m++)
	{data_byte[m] = *char_ptr;
	char_ptr += 1;}
	}break;
		
	case 'C':													//Convert long from UNO to string
	clear_display_buffer;
	clear_temp_buffer;
	ltoa(Long_Num_from_UNO, temp_buffer, 10);
	temp2display_buffer;										//Reverse string prior to display	
	break;
			
	/*case 'D': 													//Convert float from UNO to string
	Float_Num_from_UNO  = *float_ptr;
	ftoaL(Float_Num_from_UNO);
	Combine_dp;		 
	Insert_sign;
	Remove_lagging_zeros;
	temp2display_buffer;										//Reverse string prior to display
	if (expt){Left_justify_number;
	Add_exponent ();}
	break;*/
		
	case 'D': 													//Convert float from UNO to string
	Float_Num_from_UNO  = *float_ptr;
	if (ftoaL(Float_Num_from_UNO)){
	Combine_dp;		 
	Insert_sign;
	Remove_lagging_zeros;
	temp2display_buffer;										//Reverse string prior to display
	if (expt){Left_justify_number;
	Add_exponent ();}}
	break;	
		
		
		
	case 'E':													//Return binary number (long or float) to UNO
	for(int m = 0; m <= 7; m++)
	temp_buffer[m] = display_buffer[m];							//Flash display
	clear_display_buffer;
	_delay_ms(100);
	for(int m = 0; m <= 7; m++)
	display_buffer[m] = temp_buffer[m];
	break;
	
	case 'F': break;											//Resets ATtiny1606									
	case 'G': break;											//Toggles brightness
	case 'H': break;											//Displays 3 char numbers horizontally
	
	case 'I':													//Displays char as digit and binary
	for(int m = 0; m <= 7; m++)display_buffer[m] = 0;			//Clear display
	if (sign_bit == 's') {Disp_CharS (one_char);}
	if (sign_bit == 'u') {Disp_CharU (one_char);}break;
	
	
	case 'J':													//Converts time display to seconds * ten (deci seconds)
	deci_sec_counter = 10*(long)((((long)
	((display_buffer[7] -'0') * 10) + 
	((display_buffer[6] & 0x7F)-'0')) * 3600) +
	((((display_buffer[5]-'0') * 10) + 
	((display_buffer[4] & 0x7F)-'0')) * 60) + 
	(display_buffer[3]-'0') * 10 + 
	(display_buffer[2] & 0x7F) - '0');break;
	
	case 'K':	deci_sec_counter += 2;							//Increment clock counter and display
	if(deci_sec_counter == 864000)deci_sec_counter = 0;
	if (!(stop_watch_mode))Format_deci_secs_and_display();
	break;
	
	case 'L':	deci_sec_counter = Long_Num_from_UNO;			//Clock/timer display  
	Format_deci_secs_and_display();
	break;
	
	
	case 'N':	
	stop_watch_mode = 1;										//Stop watch display
	centi_sec_counter = Long_Num_from_UNO;
	Format_centi_secs_and_display();
	break;
	
	
	}
	
	
	if(transaction_type != 'G')mode = transaction_type;	
	transaction_type = 0;
	busy_flag = 0;
	}}



/*****************************************************************************************************************************/
	void Start_TCA0(void){										//Clock that controls display and FW comms port
	
	clear_display_buffer;										//Generate test display
	clear_digits;
	clear_display;
	Set_display_ports;
	display_ptr = 0;
	TCA0_SINGLE_CNT = 0;										//Initialise counter
	TCA0_SINGLE_CMP0 = display_tick;							//2mS period for 2MHz clock
	TCA0_SINGLE_CTRLA = TCA_SINGLE_CLKSEL_DIV1_gc | 1;			//Start clock with 2MHz clock
	TCA0_SINGLE_INTCTRL |= TCA_SINGLE_CMP0EN_bm;}				//Interrupt flag on compare match





/*****************************************************************************************************************************/
	ISR (TCA0_CMP0_vect){										//ISR which responds to clock ticks
	TCA0_SINGLE_INTFLAGS |= TCA_SINGLE_CMP0EN_bm;				//Clear the interrupt flag
	if(display_ptr <= 7)										//Drive the 8 display digits
	{Display_driver();
	if(display_ptr < 7){inc_display_clock;}						//Setup 2mS clock tick for first 7 digits
	else TCA0_SINGLE_CMP0 += 1800;								//setup 0.9mS clock tick for last digit
	display_ptr += 1;
	return;}
	display_ptr += 1;
	cmp0_bkp = TCA0_SINGLE_CMP0 + 2200;							//Save 1.1mS clock tick for first digit
	if (!(busy_flag))
	{inc_comms_clock;											//only poll UNO if no transactions are ongoing
	PORTA.DIR |= PIN2_bm;										//initiate start pulse
	comms_transaction();}										//Poll the UNO
	TCA0_SINGLE_CMP0 = cmp0_bkp;								//Reinstate the 1.1ms clock tick
	display_ptr = 0;}											//Set display_pointer to the first digit
		
		
		
		
		
	/*****************************************************************************************************************************/
	void Display_driver(void){
		
		switch(display_ptr){
			case 0: digit_0; break;
			case 1: digit_1; break;
			case 2: digit_2; break;
			case 3: digit_3; break;
			case 4: digit_4; break;
			case 5: digit_5; break;
			case 6: digit_6; break;
			case 7: digit_7; break;}
		
		
		switch(mode){
		case 'A': case'B': case 'C': case 'D': case 'E': 
		case 'J': case 'K': case 'L':  case 'M': case 'N':
		case 'O':
				
		Char_definition(); break;
		
		case 'a':
		
		switch (display_ptr){
			
			case 0: if(display_buffer[0] & 0x01) one_U; if(display_buffer[0] & 0x02) ONE_U;
					if(display_buffer[1] & 0x01) one_L; if(display_buffer[1] & 0x02) ONE_L;
					 break;
			
			case 1: if(display_buffer[0] & 0x04) one_U;  if(display_buffer[0] & 0x08) ONE_U;
					if(display_buffer[1] & 0x04) one_L;  if(display_buffer[1] & 0x08) ONE_L; 
					break;
					
			case 2: if(display_buffer[0] & 0x10) one_U; if(display_buffer[0] & 0x20) ONE_U;
					if(display_buffer[1] & 0x10) one_L; if(display_buffer[1] & 0x20) ONE_L;
					break;
					
			case 3: if(display_buffer[0] & 0x40) one_U;  if(display_buffer[0] & 0x80) ONE_U;
					if(display_buffer[1] & 0x40) one_L;  if(display_buffer[1] & 0x80) ONE_L;
					break;
					
					
			case 4: if(display_buffer[2] & 0x01) one_U; if(display_buffer[2] & 0x02) ONE_U;
					if(display_buffer[3] & 0x01) one_L; if(display_buffer[3] & 0x02) ONE_L;
					break;
			
			case 5: if(display_buffer[2] & 0x04) one_U;  if(display_buffer[2] & 0x08) ONE_U;
					if(display_buffer[3] & 0x04) one_L;  if(display_buffer[3] & 0x08) ONE_L;
					break;
			
			case 6: if(display_buffer[2] & 0x10) one_U; if(display_buffer[2] & 0x20) ONE_U;
					if(display_buffer[3] & 0x10) one_L; if(display_buffer[3] & 0x20) ONE_L;
					break;
			
			case 7: if(display_buffer[2] & 0x40) one_U;  if(display_buffer[2] & 0x80) ONE_U;
					if(display_buffer[3] & 0x40) one_L;  if(display_buffer[3] & 0x80) ONE_L;
					break;
					}break;
		
		
		case 'b': case 'H': Seg_definitions(); break;
		
		case 'I': Char_definition();
		switch(display_ptr){
			case 4: if(one_char & 0x01) {one;} if(one_char & 0x02) {ONE;} break;
			case 5: if(one_char & 0x04) {one;} if(one_char & 0x08) {ONE;} break;
			case 6: if(one_char & 0x10) {one;} if(one_char & 0x20) {ONE;} break;
			case 7:if(one_char & 0x40) {one;} if(one_char & 0x80) {ONE;} break; }break;

		}
		Start_TCB0(brightness_control);										//TCB0 controls the brightness
		}									

	
		
		
		
	/******************************************************************************************************************/
	void Char_definition()
	{switch (display_buffer[display_ptr]){
	case '0': zero; break;
	case '1': one; break;
	case '2': two; break;
	case '3': three; break;
	case '4': four; break;
	case '5': five; break;
	case '6': six; break;
	case '7': seven; break;
	case '8': eight; break;
	case '9': nine; break;
	case '-': minus; break;
	case '_': underscore; break;
			
	case 'E': case 'e': exponent; break;
	case ('0' | 0x80): zero_point; break;
	case ('1' | 0x80): one_point; break;
	case ('2' | 0x80): two_point; break;
	case ('3' | 0x80): three_point; break;
	case ('4' | 0x80): four_point; break;
	case ('5' | 0x80): five_point; break;
	case ('6' | 0x80): six_point; break;
	case ('7' | 0x80): seven_point; break;
	case ('8' | 0x80): eight_point; break;
	case ('9' | 0x80): nine_point; break;
	case ('-' | 0x80): minus_point; break;}}
	

/*******************PCB111000_CP2102**********************************************************************/
void Seg_definitions(){ char m=0;
	switch(display_ptr){
		case 0: m = 0x01; break;
		case 1: m = 0x02; break;
		case 2: m = 0x04; break;
		case 3: m = 0x08; break;
		case 4: m = 0x10; break;
		case 5: m = 0x20; break;
		case 6: m = 0x40; break;
		case 7: m = 0x80; break;}
	if (display_buffer[0] & m) PORTB.OUT &= (~(seg_a));
	if (display_buffer[1] & m) PORTC.OUT &= (~(seg_g));
	if (display_buffer[2] & m) PORTB.OUT &= (~(seg_d));
	if (display_buffer[3] & m) PORTA.OUT &= (~(seg_b));
	if (display_buffer[4] & m) PORTB.OUT &= (~(seg_c));
	if (display_buffer[5] & m) PORTA.OUT &= (~(seg_e));
	if (display_buffer[6] & m) PORTC.OUT &= (~(seg_f));}
	



	/*****************************************************************************************************************************/
	void Start_TCB0(int BC){						//Controls the display intensity
	TCB0_CNT = 0;									//Initialise counter
	TCB0_CCMP = BC;									//1.75mS for full brightness 0.25ms for low brightness
	TCB0_CTRLA = 1;									//Start the clock
	TCB0_INTCTRL = 1;}								//Interrupt flag on compare match

		
	ISR (TCB0_INT_vect){							//Clear display
	TCB0_INTFLAGS = 1;								//Clear interrupt flag
	TCB0_CTRLA = 0;									//Stop the clock	
	clear_digits; clear_display;}	
	
	
	int mag(int m){									//Convert negative number to positive
		int n = 0;
		if (m < 0)n = m * (-1);
		else n = m;
		return n;}
		
		
		
/*********************************************************************/
void Disp_CharS(signed char n){ 
unsigned char i; signed char sign;
for(int m = 0; m <= 3; m++){display_buffer[m] = '\0';}
if (n == -128) {display_buffer[0] = '8';display_buffer[1] = '2';display_buffer[2] = '1';display_buffer[3] = '-';}
else{
if ((sign = n) < 0) n = -n;
i=0; 
do{
display_buffer[i] = n % 10  +  '0';
i++;
}while((n/=10)>0);
if (sign < 0)display_buffer[i] = '-';}}


/*********************************************************************/
void Disp_CharU(unsigned char n){ 
unsigned char i; 
for(int m = 0; m <= 3; m++){display_buffer[m] = '\0';}
i=0; 
do{
display_buffer[i] = n % 10  +  '0';
i++;
}while((n/=10)>0);}

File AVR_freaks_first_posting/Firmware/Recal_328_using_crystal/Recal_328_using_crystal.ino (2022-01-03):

 
/*
328_Recall Routine uses the watch crystal as a time standard
It uses two timers T1 and T2.
T1 and clocked at 1MHz using the internal 8HMz RC clock.
T2 is clocked using a 32.768KHz watch crystal.

T2 counts from zero to 255 and overflows every 7.8125mS during which time T1 counts 
up to 7,812 if the RC clock is running at exactly 8MHz.  OSCCAL is adjusted until the error is 1% or less.

*/


#include "Project_header.h"

unsigned char OSCCAL_default;                                  //Factory calibration value (usually enables comms with PC)
unsigned char OSCCAL_2_percent;                                //Calibration accuracy of betwee 1% and 2%
unsigned char OSCCAL_test;                                     //Takes on values of between 15 and 240
unsigned char OSCCAL_previous;



int main(void)
{char keypress;
unsigned char User_cal;                                        //User enters the value following calibration
 
long error = 0;                                                 //Calibration error
char error_percent = 0;

 
setup_328_HW;                                                   //Sets watchdog IO and UART
initialise_crystal;
sei();

OSCCAL_default = OSCCAL;                                        //Default value provided by the chip
OSCCAL_2_percent = OSCCAL;                                      //Interim value of OSCCAL guaranteed to enable PC comms
OSCCAL_test = 14;                                               //Test values OSCCAL starting with 15 and ending with 240


/***********Plot OSCCAL againt error using watch crystal as standard***************
for(int m = 15; m <= 245; m++){
error_percent = 
measure_cal_error(OSCCAL_default, m, &error);
print_cal_result(m, error, error_percent);
_delay_ms(20);
}while(1);
***********************************************************************************/


while(1){OSCCAL_test += 1;
error_percent = 
measure_cal_error(OSCCAL_default, OSCCAL_test, &error);         //Returns actual error and percentage error 
if ((error_percent <= 1) && (error_percent >= -1))break; 
else if (!(OSCCAL_test%8))Serial.write('.');}
OSCCAL_2_percent = OSCCAL_test;                                 //Save OSCCAL giving and error of between 1 and 2%

Serial.write("\r\n\r\nOSCCAL\t  Error\t   %error\r\n");
_delay_ms(10);                                                  //Complete printing before changong OSCCAL

for (int m = OSCCAL_2_percent; m <= 225; m++){                  //Continue testing OSCCAL values
OSCCAL_test = m;
error_percent = 
measure_cal_error(OSCCAL_2_percent, OSCCAL_test, &error);        //Pointer enables two values to be returned
if ((error_percent <= 1) && (error_percent >= -1))              //Print out results giving an error of < 2%
{print_cal_result(OSCCAL_test, error, error_percent);}
 OSCCAL_test += 1;}                                              //Next value of OSCCAL
 
User_cal = 0;
Serial.write("\r\rUser cal? Terminate with -cr-\r\n");

User_cal = Int_from_KBD();                                      //Acquire user cal
error_percent = 
measure_cal_error(OSCCAL_2_percent, User_cal, &error);          //Reject if results in poor calibration
if ((error_percent <= 1) && (error_percent >= -1));
else {Serial.write("Excessive error!");SW_reset;} 

if ((eeprom_read_byte((uint8_t*)0x3FF) > 0x0F)\
&&  (eeprom_read_byte((uint8_t*)0x3FF) < 0xF0) && 
(eeprom_read_byte((uint8_t*)0x3FF)\
== eeprom_read_byte((uint8_t*)0x3FE))) {
OSCCAL_previous = eeprom_read_byte((uint8_t*)0x3FF);}               //Save result of previous calibration if done
else OSCCAL_previous = 0;

eeprom_write_byte((uint8_t*)0x3FF, User_cal);                      //Save user cal in EEPROM 
eeprom_write_byte((uint8_t*)0x3FE, User_cal);
eeprom_write_byte((uint8_t*)0x3FD, OSCCAL_default);                 //Save default OSCCAL in EEPROM

Serial.write("\r\nSaved to EEPROM");

OSC_CAL;                                                            //Retrieves OSCCAL value from EEPROM

error_percent = measure_cal_error(OSCCAL, OSCCAL, &error);          //Check error values and 
print_cal_result(OSCCAL, error, error_percent);                     //print the out

Serial.write("\r\n\r\nDefault value of OSCCAL is\t   ");
Serial.print(OSCCAL_default);
_delay_ms(5);                                                       //Required to complete printing

if(OSCCAL_previous){
Serial.write("\r\nPrevious value of OSCCAL was  ");
Serial.print(OSCCAL_previous);
_delay_ms(5);}

Serial.write("\r\n\r\nPOR with reset control switch pressed to restore p/r/t/D prompt.\r\n");
_delay_ms(10);

return 1;}




/************************************************************************************************/
char measure_cal_error(unsigned char OSCCAL_OK, unsigned char OSCCAL_test, long * error ){
int EA_counter = 0;
//TCNT1_BKP = 0;
OSCCAL = OSCCAL_test; 
initialise_timers_for_cal_error();
    start_timers_for_cal_error();    
    
    while(!(TIFR2 & (1 << TOV2)));              //Wait for T2 to overflow for first time
    TIFR2 |= (1 << TOV2);                       //Reset overflow flag
    get_error(EA_counter);                      //get result and ignore it
    EA_counter = 1;                             //increment counter
    while(!(TIFR2 & (1 << TOV2)));              //Wait for T2 to overflow for second time
    TIFR2 |= (1 << TOV2);                       //Reset overflow flag
OSCCAL = OSCCAL_OK;  
*error = get_error(EA_counter);
return 100 * long(*error)/7812;}


/************************************************************************************************/
int get_error (char EA_counter){
int TCNT1_BKP, target_res;
target_res = 7812;                                
TCCR1B = 0;                                   //Halt T1
TCNT1_BKP = TCNT1;                            //Copy the value of TCNT1
TCNT1 = 0;                                    //Clear TCNT1
TCCR1B = cal_speed;                           //Get T1 running again ASAP (Note T2 has not stopped running)

if(!EA_counter)return 0;                      //Ignore first result to allow for warm up.
else
return (TCNT1_BKP - target_res);}             //return second error result


/************************************************************************************************/
void print_cal_result(unsigned char OSCCAL_test,
long error, char percent) {
Serial.write("\r\n");                          //Sends askii chars
Serial.print(OSCCAL_test);                     //Sends number as askii string
Serial.write("\t   ");
Serial.print(error);
Serial.write("\t      ");
Serial.print(int(percent));                    //Sends char variable as askii char
//Serial.write("\t");
//Serial.print(TCNT1);
_delay_ms(5);}
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
